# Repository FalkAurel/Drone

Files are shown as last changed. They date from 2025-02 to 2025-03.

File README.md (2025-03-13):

# 🚁 Custom Drone Project  

This project documents the complete process of designing, building, and programming a fully custom drone from scratch. Unlike many DIY drone projects, this one does **not** rely on any pre-existing drone components or software. Instead, every element—from hardware drivers to flight algorithms—is built from the ground up.  

## 🛠️ Project Overview  

- **Microcontroller:** ESP32 (used as the main driver)  
- **Design Software:** FreeCAD  
- **Hardware:** Fully custom-built, including motors, frame, and electronic components  
- **Software:** No pre-existing codebases; every driver is implemented based on hardware specifications  

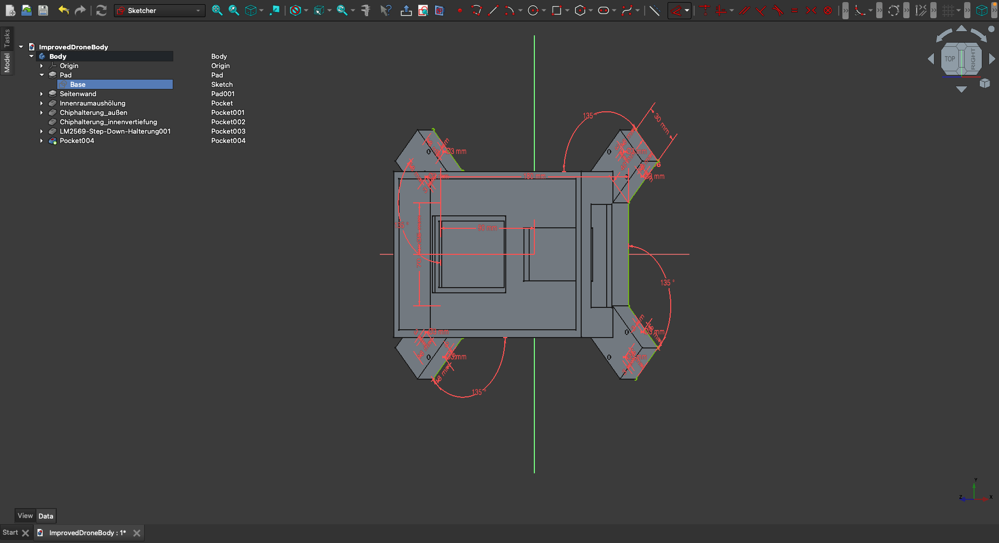
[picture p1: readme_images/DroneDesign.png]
Drone Design
  

## 📌 Features  

✅ **Custom Hardware Drivers** – Directly interact with components like gyrosensors and Electronic Speed Controllers (ESCs) without relying on third-party libraries.  
✅ **Fully Documented** – Every aspect of the project, from math equations to code logic, is extensively documented using comments and markdown files.  
✅ **Datasheets Included** – All hardware datasheets are attached to ensure transparency and reproducibility.  

## 🧠 Low-Level Hardware Control  

The codebase is built entirely from scratch, implementing precise control over essential components:  

- **Gyroscope Driver** – Interprets raw sensor data to maintain flight stability.  
- **ESC Control** – Generates PWM signals to regulate motor speed dynamically.  
- **Flight Algorithms** – Developed using mathematical models to achieve stable flight.  

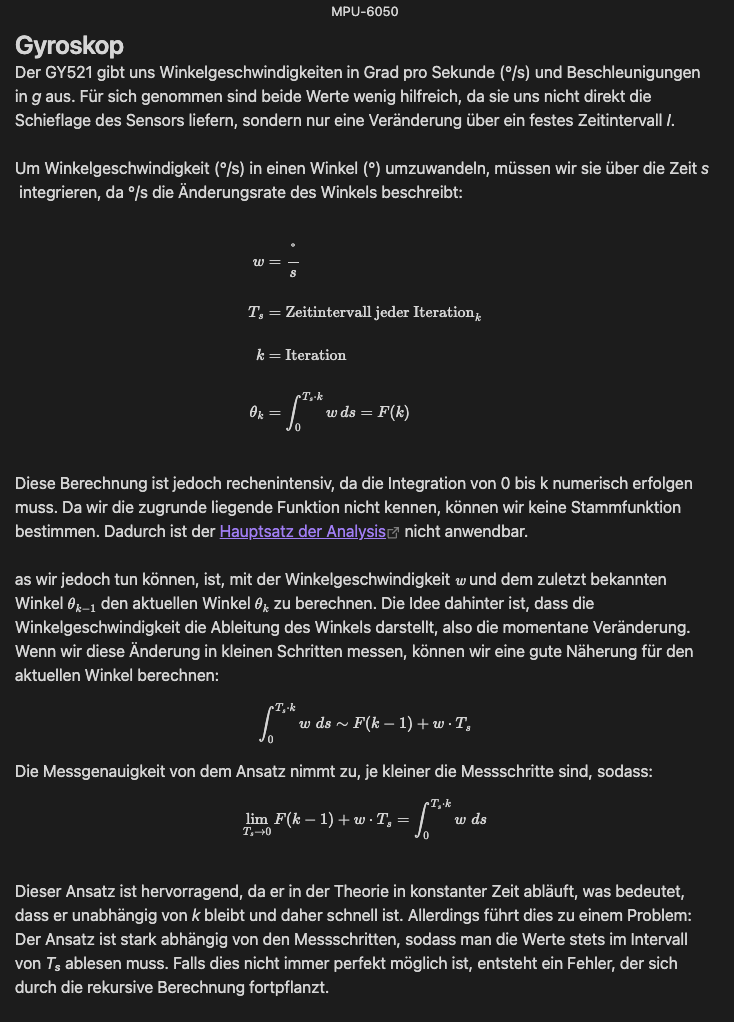
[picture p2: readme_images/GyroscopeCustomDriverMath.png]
Gyroscope Driver Math
  

## 📄 Documentation  

- **In-Depth Code Annotations** – Every function and logic structure is documented.  
- **Mathematical Derivations** – Flight physics, stabilization techniques, and control algorithms are explained.  
- **Reference Materials** – All datasheets and technical references are included.  

## ✅ Implemented Features  

- [x] ESP32-based flight controller  
- [x] Custom gyroscope driver  
- [x] Custom ESC driver  
- [x] Flight stabilization algorithms  
- [x] Complete design in FreeCAD  
- [x] Full documentation of code and math 
- [x] Custom Bump/Arena Allocator
- [x] Implement Wifi

## 📌 To-Do List
- [ ] Implement UDP or custom Data Transfer Protocol
- [ ] Implement Mulithreading
- [ ] Implement PID tuning for better flight stability
- [ ] Add remote control functionality
- [ ] Optimize power efficiency
- [ ] Improve motor calibration
- [ ] Perform real-world flight tests

## 🚀 Get Involved  

If you're interested in custom drone development, feel free to contribute, ask questions, or suggest improvements!

## Special Thanks
App Devlopment by [@MaeschDEV](https://github.com/MaeschDEV)

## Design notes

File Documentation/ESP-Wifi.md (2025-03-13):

Der ESP32 besitzt ein eingebautes Wifi-Modul. Das Wifi-Modul nutzt intern das Wifi -und Bluetoothradio. Diese Hardwarekomponente **muss** aktiviert werden. Anschließend muss entschieden werden, ob wir in STA oder AP-Modus schalten. Beide Modi haben Vor -und Nachteile, sodass oftmals eine STA/AP-Kombination gewählt wird.
In unserem Fall haben wir nur ein sehr eingeschränktes Nutzungsspektrum. Weshalb wir keine Kombination verwenden werden. 

| Modus | Anwendung |
| ----- | --- |
| AP | Der ESP32 stellt ein eigenes WLAN-Netzwerk bereit, mit dem sich andere Geräte verbinden können. Nützlich für lokale Steuerungen oder wenn keine bestehende Infrastruktur vorhanden ist. |
| STA | Der ESP32 verbindet sich mit einem bestehenden WLAN-Netzwerk, um Daten mit anderen Geräten oder dem Internet auszutauschen. Geeignet für IoT-Anwendungen und Cloud-Kommunikation. |
In unserem Fall wollen wir, dass die Drohne unabhängig von Netzempfang in der Natur funktioniert. Wichtig hierbei wird also die AP-Funktionalität sein. Die Drohne sollte ihr eigenes WLAN-Netzwerk bereitstellen. 

Um so etwas zu vollbringen, müssen wir die Drohne einrichten. Wir belassen viele Einstellungen bei den Standardeinstellungen.

| AP-Einstellungen  | Werte |
| --- | --- |
| SSID | Flightcontroller |
| Password | FlightcontrollerPassword |
| Sicherheit | WPA2Personal |
| max. Verbindungen | 2 |

Das ESP-Wifi nutzt statische IP-Adressen. Aus diesem Grund müssen die Wifi-Einstellungen von dem Endgerät auch angepasst werden.

| Wifi-Einstellungen | Werte |
| --- | --- |
| IP | Statisch (Standard ist DHCP) |
| IP-Adresse | 192.168.2.x (1 < x < 256) |

## Anwendung

Das ESPWifi-Modul muss erst kreiert werden.
```rust
let mut wifi: Wifi<Uninit> = Wifi::new(timg0.timer0, peripherals.RNG, peripherals.RADIO_CLK).unwrap();
```

Das ESPWifi-Modul muss anschließend initialisiert werden. Bei der Initialisierung werden SSID und Password gesetzt und die maximale Anzahl an zugelassenen Verbindungen.
```rust
wifi.init(peripherals.WIFI, "Flightcontroller", "FlightcontrollerPassword", 2).unwrap()
```
## Error

Das ESPWifi-Modul kann auf verschiedene Weisen verfehlen.

| Error | Grund |
| --- | --- |
| WifiRadioInitialization | Wifi -und Bluetoothradioaktivierung fehlerhaft |
| AccessPointConfig | Access Point Konfiguration fehlerhaft in Initialisierung |
| StartAP | Access Point start fehlerhaft in Initialisierung |
| UTF8Parsing | UTF8-String beinhaltet nicht ASCII-Code |

## UDP Layer

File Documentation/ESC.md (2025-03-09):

Quellen
- https://www.youtube.com/watch?v=oKFi5KRNqHE&t=31s

![[30A_BLDC_ESC_Product_Manual.pdf]]

Der 30A BLDC ESC ist ein elektronischer Speed Controller, der bei 5V und max. 3A arbeitet. Die Motoren werden durch [PWM](https://de.wikipedia.org/wiki/Pulsdauermodulation) angesteuert. Durch ein Kontrollsignal kann der ESC angesteuert werden. 

## PWM (Pulsdauermodulation)
https://en.wikipedia.org/wiki/Pulse-width_modulation

## Todo 
- Füge Pull-up wiederstande hinzu

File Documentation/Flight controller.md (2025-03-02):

```toml
[package]
edition = "2021"
name    = "flight_controller"
version = "0.1.0"

[[bin]]
name = "flight_controller"
path = "./src/bin/main.rs"

[dependencies]
embedded-io = "0.6.1"
embedded-io-async = "0.6.1"
esp-alloc = { version = "0.6.0" }
esp-backtrace = { version = "0.15.0", features = [
  "esp32",
  "exception-handler",
  "panic-handler",
  "println",
] }
esp-hal = { version = "0.23.1", features = ["esp32", "unstable"] } # defmt
esp-println = { version = "0.13.0", features = ["esp32", "log"] }
esp-wifi = { version = "0.12.0", default-features = false, features = [
  "ble",
  "coex",
  "esp-alloc",
  "esp32",
  #"log",
  #"utils",
  "wifi",
] }

heapless = { version = "0.8.0", default-features = false }
log = { version = "0.4.21"  } # https://docs.esp-rs.org/esp-hal/esp-wifi/0.12.0/esp32/esp_wifi/index.html
smoltcp = { version = "0.12.0", default-features = false, features = [
  "medium-ethernet",
  "multicast",
  "proto-dhcpv4",
  "proto-dns",
  "proto-ipv4",
  "socket-dns",
  "socket-icmp",
  "socket-raw",
  "socket-tcp",
  "socket-udp",
] }
# for more networking protocol support see https://crates.io/crates/edge-net
bleps = { git = "https://github.com/bjoernQ/bleps", package = "bleps", rev = "a5148d8ae679e021b78f53fd33afb8bb35d0b62e", features = [
  "async",
  "macros",
] }

critical-section = "1.2.0"
esp-hal-embassy = { version = "0.6.0", features = ["esp32"] }
static_cell = { version = "2.1.0", features = ["nightly"] }
libm = "0.2.11"
fugit = "0.3.7"

[profile.dev.package.esp-wifi]
opt-level = 3

[profile.dev]
# Rust debug is too slow.
# For debug builds always builds with some optimization
opt-level = "s"

[profile.release]
codegen-units    = 1     # LLVM can perform better optimizations using a single thread
debug            = 2
debug-assertions = false
incremental      = false
lto              = 'fat'
opt-level        = 's'
overflow-checks  = false
```

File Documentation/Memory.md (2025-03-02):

Dieses Modul dokumentiert die Implementierung einer eigenen Speicherverwaltung. Die Speicherverwaltung wird als [linked list alloctator](https://os.phil-opp.com/allocator-designs/#linked-list-allocator) implementiert. Weiterführend wird das ESP32 Technical Reference Manual ver. 5.3 verwendet. 

![[datasheets/ESP32_technical_reference.pdf]]

## Linked List Allocator

### Grundlegende Überlegungen

Der Linked List Allocator nutzt eine linked List, um die freien Speicherregionen zu verwalten. Die Idee ist, dass der Speicher sich selbst verwaltet, indem jeder Block auf den nächsten freien Block zeigt. Sobald kein Block mehr auf einen anderen zeigt, muss der Speicher voll sein. 

Zunächst beginnt man mit einem Block, der den ganzen Speicher abdeckt. Sobald Speicher benötigt wird, wird aus dem Block ein kleiner rausgeschnitten, der nun reserviert für eine Ressource genutzt wird. Das *"Rausschneiden"* beginnt immer am Anfang, sodass der Kopf der linked List auf immer auf den ersten freien Block zeigt.

Bei der Freigabe der speicherkonsumierenden Ressource wird auch der Speicher an den Allocator zurückgegeben. Das zurückgeben kann auf verschiedene Weisen funktionieren. Mann könnte versuchen den Block an seinen ursprünglichen Platz einzufügen oder ihn einfach an den Anfang der `free list` schieben. Beides hat Vor -und Nachteile.
Ersteres wäre der naive Ansatz, der theoretisch weniger Speicher pro Node header verbraucht, da die absolute Position nicht definiert werden muss, sondern durch die relative Lage in der `free list` bestimmt werden kann. Dieser Vorteil kommt auf Kosten der Laufzeit, da bei jedem `free` eine konstante Suche laufen muss (Theoretisch ist es eine O(*n*) Operation, aber da die Größe der `free_list` bereits durch den ersten Block definiert ist, hat sie eine feste obere Grenze, die sich nicht mehr verändern kann (definiert durch die Speichergröße)).
Wenn man aber jedem Block seine Adresse neben der Größe mitgibt (system width integer), dann kann man den Block einfach an den Anfang anhängen, sodass die Operation O(1) ist. Aus diesem Grund werden wir den letzteren Ansatz implementieren.

### Speicherfragmentierung

Jeder der eine linked List implementiert hat, weiß, dass sie kein kontinuierliches Speichersegment nutzt, sondern fragmentartig im Speicher lebt. Das ist zugleich die Stärke und Schwäche dieser Datenstruktur, es ermöglicht uns Sachen zu speichern, die nicht mehr in einem Stück in den Speicher passen, allerdings fragmentiert es auch den Speicher. Ein fragmentierter Speicher könnte theoretisch noch Elemente speichern, hätte er genug kontinuierlichen Speicher am Stück.
Die Fragmentierung hat zwei Ursachen: Alignment und unterschiedliche Objekte mit unterschiedlichen Lebenszeiten. 
Alignment ist nicht (leicht) zu beheben. Moderene Prozessoren sind darauf ausgelegt Daten von Adressen auszulesen, die ein vielfaches von 2 sind. Aus diesem Grund werden wir nicht dieses Problem angehen. 
Die Speicherfragmentierung durch Objekte mit verschiedenen Lebenszeit können wir softwaretechnisch angehen. Wir können nicht die Lebenszeiten der Objekte bestimmen, aber wir können die freigegebenen Speicherblöcke manipulieren. Wenn man zwei oder mehr Blöcke findet, die ein kontinuierliches Speichersegment beschreiben, kann man diese Blöcke in einen größeren zusammenführen. Eine weitere Vorgehensweise ist, `best-fit` Allokation zu nutzen. Wir suchen die ganze `free list` nach dem kleinsten passenden Block ab. Diese Optimierung sollte aber optional sein, da sie nicht effektiv in einem hot codepath ist.

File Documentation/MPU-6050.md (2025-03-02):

**Unser** Gyrosensor beinhaltet ein 3-Achsen-Gyroskop und einen 3-Achsen-Beschleunigungssensor. Und einige weitere Funktionalitäten, die nicht in unserem Kontext wichtig sind. Die MPU-60X0-Serie besitzt je drei 16-bit [ADC](https://de.wikipedia.org/wiki/Analog-Digital-Umsetzer) für Gyro -und Beschleunigungssensor. Damit ist ein leichtes Auslesen der Daten gewährleistet.
Weiterhin verfügt der Chip einen FIF0-1024-Bytes-Buffer, sodass man Bulk reads machen kann.

Unser Sensor nutzt intern den MPU-6050-IMU.
![[datasheets/MPU-6050-IMU-datasheet.pdf]]

Als Interface zu dem Chip nutzen wir den GY-521
![[gy-521_mpu-6050_3-axis_gyroscope_and_acceleration_sensor_en.pdf]]

## Konfigurationen

Der GY512 kann in Sachen Messmetriken und Messtoleranz konfiguriert werden. Die Konfiguration erfolgt über Register in die Werte geschrieben werden.

| Register | Funktion |
| --- | --- |
| `0x1A` | [DLPF](DLPF) und FSYNC |
| `0x1B` | GYRO_CONFIG |
| `0x1C` | ACCEL_CONFIG |
| `0x6B` | PWR_MGMT_1 |

## Power On

Der GY521 dient als eine Art von Schnittstelle zu dem unterliegenden Chip, dem MPU-6050. Der MPU-6050 ist also zunächst **nicht** eingeschaltet und befindet sich im Low-Power-Mode. Um den Chip aus dem Low-Power-Mode zu holen, schreibt man in das Register `0x6B` den Wert `0x0`.
Das Register `0x6B` ist für das Power Management zuständig. Der Wert `0x0` aktiviert eine 8Mhz (interne) CPU-Uhr. Es ist möglich eine bis zu 19.2Mhz anzuschließen, dass allerdings nur durch eine externes Signal. Für unsere Applikation ist das nicht von Nöten

![[MPU-6050-Register-0x6B.png]]

### Digital Low Pass Filter

Der Digital Low Pass Filter ermöglicht Signal von zu niedriger Frequenz auszufiltern, damit werden Störsignale gefiltert und das Signal bereinigt. 
![[MPU-6050-Register0x1A-Tabel.png]]

### Gyro Konfiguration

Mit dem Register können die °/s angegeben werden. 

![[MPU-6050-RegisterLayout-0x1B.png]]

Wobei die °/s  durch das `FS_SEL` angegeben wird.  `FS_SEL` kann folgende Werte haben:

| FS_SEL | Full Scale Range |
| --- | --- |
| 0 | ± 250 °/s |
| 1 | ± 500 °/s |
| 2 | ± 1000 °/s |
| 3 | ± 2000 °/s |

###   Beschleunigungssensor Konfiguration

Mit dem Register kann die Messgenauigkeit bis zu einer bestimmten `G`-Kraft definiert werden. Wie bei dem Gyroscope kann dafür ein Register verwendet werden, indem Fall ist es `0x1C`. Das Register `0x1C` ist identisch zu `0x1b`, nur werden die Werte anders interpretiert. 

![[MPU-6050-Register-0x1C.png]]

Die `AFS_SEL`-Bits definieren die G-Krafttoleranz. 

| AFS_SEL | Full Scale Range |
| --- | --- |
| 0 | ± 2g |
| 1 | ± 4g |
| 2 | ± 8g |
| 3 | ± 16g |

## Kommunikation

Der GY521 und der unterliegende MPU-6050 nutzen das [I²C](https://de.wikipedia.org/wiki/I²C)-Protokoll für den Datenaustausch. Der GY521 **startet immer als Slave** und erwartet von dem Master geweckt zu werden. Die Adresse des GY521 ist standardmäßig `0x68`. Sollte man den `AD0`-Pin auf high setzen, so nimmt der GY521 die Adresse `0x69` an. 

## Umrechnung in Winkel

## Gyroskop
Der GY521 gibt uns Winkelgeschwindigkeiten in Grad pro Sekunde (°/s) und Beschleunigungen in _g_ aus. Für sich genommen sind beide Werte wenig hilfreich, da sie uns nicht direkt die Schieflage des Sensors liefern, sondern nur eine Veränderung über ein festes Zeitintervall _I_.

Um Winkelgeschwindigkeit (°/s) in einen Winkel (°) umzuwandeln, müssen wir sie über die Zeit _s_ integrieren, da °/s die Änderungsrate des Winkels beschreibt:

$$
\begin{align}
w &= \dfrac{\degree}{s} \\[5mm]
T_s &= \text{Zeitintervall jeder Iteration}_k\\[5mm]
k &= \text{Iteration}\\[5mm]
\theta_k &= \int_0^{T_s \cdot k} w \, ds = F(k)
\end{align}
$$

Diese Berechnung ist jedoch rechenintensiv, da die Integration von 0 bis k numerisch erfolgen muss. Da wir die zugrunde liegende Funktion nicht kennen, können wir keine Stammfunktion bestimmen. Dadurch ist der [Hauptsatz der Analysis](https://de.wikipedia.org/wiki/Fundamentalsatz_der_Analysis) nicht anwendbar.

as wir jedoch tun können, ist, mit der Winkelgeschwindigkeit $\mathit{w}$ und dem zuletzt bekannten Winkel $\theta_{k-1}$ den aktuellen Winkel $\theta_k$ zu berechnen. Die Idee dahinter ist, dass die Winkelgeschwindigkeit die Ableitung des Winkels darstellt, also die momentane Veränderung. Wenn wir diese Änderung in kleinen Schritten messen, können wir eine gute Näherung für den aktuellen Winkel berechnen:
$$
\begin{align}
\int_0^{T_s \cdot k} w \,\,ds \sim F(k - 1) +w \cdot T_s
\end{align}
$$
Die Messgenauigkeit von dem Ansatz nimmt zu, je kleiner die Messschritte sind, sodass:
$$
\begin{align}
\lim_{T_s\to0} F(k - 1) +w \cdot T_s = \int_0^{T_s \cdot k} w \,\,ds
\end{align}
$$

Dieser Ansatz ist hervorragend, da er in der Theorie in konstanter Zeit abläuft, was bedeutet, dass er unabhängig von *k* bleibt und daher schnell ist. Allerdings führt dies zu einem Problem: Der Ansatz ist stark abhängig von den Messschritten, sodass man die Werte stets im Intervall von _Tₛ_ ablesen muss. Falls dies nicht immer perfekt möglich ist, entsteht ein Fehler, der sich durch die rekursive Berechnung fortpflanzt.

## Beschleunigungssensor

Der Beschleunigungssensor misst die Beschleunigung in Einheiten von _g_, wobei dieser Messwert die Beschleunigung entlang jeder Achse beschreibt. Wird der Sensor flach auf einen Tisch gelegt, erwartet man eine Beschleunigung von 1 _g_ entlang der Z-Achse und 0 _g_ entlang der X- und Y-Achsen. Wird der Sensor jedoch aufrecht hingestellt und um 90° entlang der X-Achse rotiert, misst er 1 _g_ entlang der X-Achse.

Durch einfaches Experimentieren lässt sich feststellen, dass die gemessene Beschleunigung entlang der Raumachsen in einer direkten Beziehung zur Orientierung des Sensors im Raum steht.

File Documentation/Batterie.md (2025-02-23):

Die Batterie muss zunächst den Spannungsbedarf der vier [Motoren](Brushless_Motor) decken. Der Spannungsbedarf liegt bei 11.1*V*. Jeder Motor kann bis zu 13A ziehen. Wir haben 4 Motoren, weshalb wir einen maximalen Stromstärkenverbrauch von 52A haben. 
Die Leistung der Batterie wird durch die Spannung und Amperestunden definiert. In unserem Fall ergibt sich die Formel:
$$
\begin{align}
Flugzeit &= \dfrac{Ah}{A} \\[5mm]

Flugzeit &= \dfrac{2.2Ah}{52A} = \dfrac{2.2h}{52} = 0.0423h = 2.538min
\end{align}
$$
0.04h sind 2.4min Betriebszeit. Aber unter normalen Bedingungen verbraucht die Drohne ca. 40% - 70% ihrer maximalen Stromstärke. Daraus ergibt sich ein gemittelter Verbrauch von 55%.
Wodurch sich unsere Betriebszeit fast verdoppelt:
$$
Flugzeit = \frac{2.2Ah}{52A} \cdot \frac{1}{0.55} = \frac{2.2Ah}{28.6A} = 0.0769h = 4.614min
$$

| Dimension | Maße |
| --- | ---- |
| Breite | 36 |
| Höhe | 23mm |
| Länge | 70mm |

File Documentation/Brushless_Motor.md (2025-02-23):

[Ressource](https://www.rotordronepro.com/guide-multirotor-motors/)

Die Wahl des Motors ist abhängig von der Größe und dem Gewicht der Drone. Der insgesamte Auftrieb des Motors sollte das doppelte des Gesamtgewichtes betragen.

## Nomenklatur
Brushless-Motoren sind in der Regel nach einer 4-stelligen Nummer sortiert. 

*DDMM*

*DD*: Dieser Wert gibt in Millimeter den Durchmesser des Motors an. 
*MM*: Dieser Wert gibt in Millimeter die Höhe des Motors an.

Je größer die Werte in *DD* und *MM*, desto mehr [Drehmoment](Physik/Drehmoment) kann der Motor aufbringen.

**KV**: beschreibt den theoretischen Anstieg von Umdrehungen pro Minute (RPM) mit jedem zusätzlichen Volt. Ein 2300 KV Motor auf eine 12.6 V Batterie könnte theoretisch 28980 RPM erreichen. 
Je höher die **KV**, desto höher die Drehgeschwindigkeit und niedriger das Drehmoment. Also haben Motoren mit einem niedrigeren **KV**-Wert ein höheres Drehmoment mit niedriger Rotationsgeschwindigkeit.

###  N und P

Die Nummer vor dem **N** gibt an, wieviele Elektromagneten in dem Stator vorhanden sind. 
Die Nummer vor dem **P** gibt an, wieviele Dauermagnete in dem Motor vorhanden sind.

### Tabellarische Übersicht

Diese Tabelle stellt gewöhnliche Motorkonfigurationen in Bezug zu der Dronengröße her

| Frame Size | Prop Size  | Motor Size | KV |
| --- | --- | --- | --- |
| <= 150mm | 3'' >= | 1306 >= | 3000 <= |
| 180mm | 4'' | 1806 | 2600 |
| 210mm | 5'' | 2204-2206  | 2300-2600 |
| 250mm | 6'' | 2204-2208  | 2000-2300 |
| 350mm | 7'' | 2208 | 1600 |
| 450mm | 8''...10'' | 2212 <= | 1000 >= |

## Unser Motor

### A2212 10T 1400KV

Weitere Quellen
- https://components101.com/motors/2212-brushless-motor
- https://www.4-max.co.uk/A2212-10T-1400kv.htm
- 

| Voltage Input Range | 6V ~12.6 V |
| --- | --- |
| Voltage Input Range | 6V ~12.6 V |
| Schub | 555g |
| Höhst Ampereverbrauch | 13A |

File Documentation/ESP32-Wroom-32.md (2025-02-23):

## Überblick

[ESP32 mit CH340 Entwicklungsplatine](https://www.amazon.de/Entwicklungsplatine-Binghe-ESP-WROOM-32-Bluetooth-kompatibel/dp/B0D8635YZ6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ÅMÅŽÕÑ&crid=U6S6FM8RXKHQ&dib=eyJ2IjoiMSJ9.sNY-5N5qC7Qc40Mxm97ZN4weJ778AWoug6y_-HIs7zJnUx6G5a_Cr7ui9T0AqxXx3C38nRJsddtw9oVz7HkEjisz5nsbp02URqzqz5KKdO1C33Xk-TpJYW610M7W6_PBUIUInRioKLPqgdexH6gLK1X_Ba-g42B5osPiGoGjxDhPiUmD_AIm_dKic2TON03oMuE5Va2wzURmNc_jQgbxTkYLvc-ipVYjj0HAakPXDNg.EPnLuabGVGk9OuytN7jRzqsqm6UfvlIYVpuc6GJIAZM&dib_tag=se&keywords=ESP32+ESP-32S+Development+Board+%283pcs%29&qid=1739624362&sprefix=esp32+esp-32s+development+board+3pcs+%2Caps%2C102&sr=8-9) ist ein Chip mit WiFi -und Bluetoothanbindung. Intern wird ein [ESP32-DOWDQ6-Chip](https://www.espressif.com/sites/default/files/documentation/esp32_datasheet_en.pdf) verwendet.
Die technischen Hardwaredaten des Chips sind hier gelistet:

| Item | Spezifikation |
| --- | --- |
| Integrierter Kristall | 40Mhz |
| SPI flash | 4MB |
| Operating voltage / Power supply | 3.0 ~3.6V |
| Operating Current | Average: 80mA |
| Minimum current delivered by power supply | 500mA |
| Package size | 18mm x 25.5mm x 3.10mm |
| CPU Architecture | dual-core [Xtensa]() 32-bit LX6 microprocessor |

Weitere Daten sind im Datenblatt zu finden, für die jetzige Implementation langen die Daten.

## Pin Definitionen

![[ESP32-Wroom-32-Pinout.jpg]]

| Name | No. | Type | Function |
| --- | --- | ---- | --- |
| GND | 1 | P | Ground |
| 3V3 | 2 | P | Power supply |
| EN | 3 | I | Module-enable signal. Active high |
| SENSOR_VP | 4 | I | GPIO36, ADC1_CH0, RTC_GPIO0 |
| SENSOR_VN | 5 | I | GPIO39, ADC1_CH3, RTC_GPIO3 |
| IO34 | 6 | I | GPIO34, ADC1_CH6, RTC_GPIO4 |
| IO35 | 7 | I | GPIO35, ADC1_CH7, RTC_GPIO5 |
| IO32 | 8 | I/O  | GPIO32, XTAL_32K_P (32.768 kHz crystal oscillator input), ADC1_CH4, TOUCH9, RTC_GPIO9  |
| IO33 | 9 | I/O  | GPIO33, XTAL_32K_N (32.768 kHz crystal oscillator output), ADC1_CH5, TOUCH8, RTC_GPIO8 |
| IO25 | 10  | I/O  | GPIO25, DAC_1, ADC2_CH8, RTC_GPIO6, EMAC_RXD0 |
| IO26 | 11  | I/O  | GPIO26, DAC_2, ADC2_CH9, RTC_GPIO7, EMAC_RXD1 |
| IO27 | 12  | I/O  | GPIO27, ADC2_CH7, TOUCH7, RTC_GPIO17, EMAC_RX_DV |
| IO14 | 13  | I/O  | GPIO14, ADC2_CH6, TOUCH6, RTC_GPIO16, MTMS, HSPICLK, HS2_CLK, SD_CLK, EMAC_TXD2 |
| IO12 | 14  | I/O  | GPIO12, ADC2_CH5, TOUCH5, RTC_GPIO15, MTDI, HSPIQ, HS2_DATA2, SD_DATA2, EMAC_TXD3 |
| GND | 15  | P | Ground |
| IO13 | 16  | I/O  | GPIO13, ADC2_CH4, TOUCH4, RTC_GPIO14, MTCK, HSPID, HS2_DATA3, SD_DATA3, EMAC_RX_ER |
| SHD/SD2*  | 17  | I/O  | GPIO9, SD_DATA2, SPIHD, HS1_DATA2, U1RXD |
| SWP/SD3*  | 18  | I/O  | GPIO10, SD_DATA3, SPIWP, HS1_DATA3, U1TXD |
| SCS/CMD*  | 19  | I/O  | GPIO11, SD_CMD, SPICS0, HS1_CMD, U1RTS |
| SCK/CLK*  | 20  | I/O  | GPIO6, SD_CLK, SPICLK, HS1_CLK, U1CTS |
| SDO/SD0*  | 21  | I/O  | GPIO7, SD_DATA0, SPIQ, HS1_DATA0, U2RTS |
| SDI/SD1*  | 22  | I/O  | GPIO8, SD_DATA1, SPID, HS1_DATA1, U2CTS |
| IO15 | 23  | I/O  | GPIO15, ADC2_CH3, TOUCH3, MTDO, HSPICS0, RTC_GPIO13, HS2_CMD, SD_CMD, EMAC_RXD3 |
| IO2 | 24  | I/O  | GPIO2, ADC2_CH2, TOUCH2, RTC_GPIO12, HSPIWP, HS2_DATA0, SD_DATA0 |
| IO0 | 25  | I/O  | GPIO0, ADC2_CH1, TOUCH1, RTC_GPIO11, CLK_OUT1, EMAC_TX_CLK |
| IO4 | 26  | I/O  | GPIO4, ADC2_CH0, TOUCH0, RTC_GPIO10, HSPIHD, HS2_DATA1, SD_DATA1, EMAC_TX_ER |
| IO16 | 27  | I/O  | GPIO16, HS1_DATA4, U2RXD, EMAC_CLK_OUT |
| IO17 | 28  | I/O  | GPIO17, HS1_DATA5, U2TXD, EMAC_CLK_OUT_180 |
| IO5 | 29  | I/O  | GPIO5, VSPICS0, HS1_DATA6, EMAC_RX_CLK |
| IO18 | 30  | I/O  | GPIO18, VSPICLK, HS1_DATA7 |
| IO19 | 31  | I/O  | GPIO19, VSPIQ, U0CTS, EMAC_TXD0 |
| NC | 32  | - | - |
| IO21 | 33  | I/O  | GPIO21, VSPIHD, EMAC_TX_EN |
| RXD0 | 34  | I/O  | GPIO3, U0RXD, CLK_OUT2 |
| TXD0 | 35  | I/O  | GPIO1, U0TXD, CLK_OUT3, EMAC_RXD2 |
| IO22 | 36  | I/O  | GPIO22, VSPIWP, U0RTS, EMAC_TXD1 |
| IO23 | 37  | I/O  | GPIO23, VSPID, HS1_STROBE |
| GND | 38  | P | Ground |

## Einrichten einer Rust-Entwicklungsumgebung

Der ESP32-WROOM kann in Rust sowohl in `no_std` als auch in `std` beschrieben werden. Die Besonderheit liegt in der Leistung und Entwicklungsgeschwindigkeit. Für schnelle, rapide Entwicklung eignet sich die `std`-Version, während `no_std` für Leistung gedacht ist.
Für dieses Projekt nutzen wir erst die `std`-Version, sollte irgendwann Leistung ein Problem werden, werden wir den Code umschreiben in die `no_std`-Version.
In beiden Fällen müssen wir für die [Xtensa](https://dl.espressif.com/github_assets/espressif/xtensa-isa-doc/releases/download/latest/Xtensa.pdf)-Architektur kompilieren. Dafür nutzt man einen [Cross-Compiler](https://de.wikipedia.org/wiki/Cross-Compiler). Rust kann das automatisch, da es LLVM als Compiler-Backend verwendet, weshalb wir nur noch die Architektur spezifizieren müssen.
Weiterhin werden wir die virtuelle Umgebung [Docker](https://www.docker.com) verwenden, da ich die Toolchain nicht  auf meinem System einrichten kann und man am Ende nur noch das Docker Image entfernen muss, wenn man mit dem Projekt fertig ist.

### Installieren von Rust Templates

Mit den folgenden Modulen lassen sich Rust-Projekt-Templates generieren. Das ist optional, jedoch empfohlen, da diese eine lokale Toolchain spezifizieren. 

- [cargo-generate](https://crates.io/crates/cargo-generate) Templategenerator. Nutzt bereits git repositories, um ein Projekttemplate zu generieren
- [espflash](https://github.com/esp-rs/espflash) ermöglicht das Brennen und Löschen von Code. Weiterhin kann es den Serial-Port in der Konsole ausgeben
- [esp-generate](https://github.com/esp-rs/esp-generate) Templategenerator für `no_std`

```bash
cargo install cargo-generate espflash esp-generate
```

Es gibt zwei Möglichkeiten, um ein Projekt zu generieren:
1. Man nutzt `esp-generate`, um ein `no_std` Projekt herzustellen.
2.  Man nutzt `cargo generate esp-rs/esp-idf-template cargo` um ein `std`Projekt  herzustellen.
In beiden Fälle muss man in den Erstelloptionen `devcontainer` hinzufügen.

In beiden fällen wird im Hauptreiter des Projektes ein Ordner namens `.devcontainer`, welcher unsere `Dockerfile` enthält. 

Um das Dockerimage zu bauen nutze diesen Befehl:

```bash
docker image build -t <name> -f .devcontainer/Dockerfile .
```

Um es auszuführen nutze diesen Befehl:

```
docker run --mount type=bind,source="$(pwd)",target=/workspace,consistency=cached -it <name> /bin/bash
```

Ich empfehle für den letzteren Befehl einen Shortcut im Projekt anzulegen, anstatt den Befehl immer auszuschreiben, nutze ein ShellScript:

```bash
echo "docker run --mount type=bind,source="$(pwd)",target=/workspace,consistency=cached -it <name> /bin/bash" >> start_docker.sh
```

Je nach Dockerfile Konfiguration, hat man einen anderen Startpunkt. Um das Projekt ausführen muss man in den **workspace** Ordner navigieren, sofern man in Docker Zugang zu USB-Serial-Peripherals hat, kann man einfach sein Projekt mit `cargo run` ausführen und auf den Chip brennen. 
Andernfalls muss man mit `cargo build` die ELF-Datei bauen und dann manuell in der natürlichen Umgebung, also außerhalb von Docker, mit `espflash` auf den Chip bringen.

## Pin Mapping

| Pin | Purpose |
| --- | --- |
| 21  | SDA ([MPU-6050](MPU-6050.md)) |
| 22  | SCL([MPU-6050](MPU-6050.md))  |
| | |

## Nützliche Ressourcen

- https://docs.sunfounder.com/projects/esp32-starter-kit/en/latest/components/component_esp32_extension.html
-

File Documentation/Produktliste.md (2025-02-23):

[Motorset](https://www.amazon.de/-/en/Brushless-Outrunner-Aircraft-KKmulticopter-Quadcopter/dp/B07VR9FR6R?th=1)
[Gyrosensor MPU6050](https://www.amazon.de/ARCELI-Beschleunigungssensor-Motion-Sensing-Spiele-Fußgänger-Navigatoren-Haltungs-Verknüpfungen/dp/B0CLS2JY43/ref=sr_1_4?dib=eyJ2IjoiMSJ9.Q1s4aL4ayXqk7UIPMXERyoUjo7V3x9kSy2_3wUMEX3W-j7ZHBimOVjXUfKHPS_QvJ-W93_beybfy9Ib0V8I2ghw3DEcoKUuRvoelAoWNJaxvq8mEVNC7bP0dFBZRtbTm8dxX-kcHN5gIEbdduI8ZfIpOwxzw37atD5U66KBVW4ffu6EWG73vCWATkODSq2OaV09XmXFpXYg2p5tPxm86MjZWlJ_y_-yEE-TeBphQe-A.QeQRLMoQNpzT0iRAtsUzZL6A19gBbmvWm5ddlR2oMFo&dib_tag=se&keywords=mpu6050&qid=1739530825&sr=8-4)
[Akku]()
[ESC](https://www.amazon.de/gp/product/B0BD3XTBLD/ref=ewc_pr_img_1?smid=AHJIHYSV33HO3&psc=1)

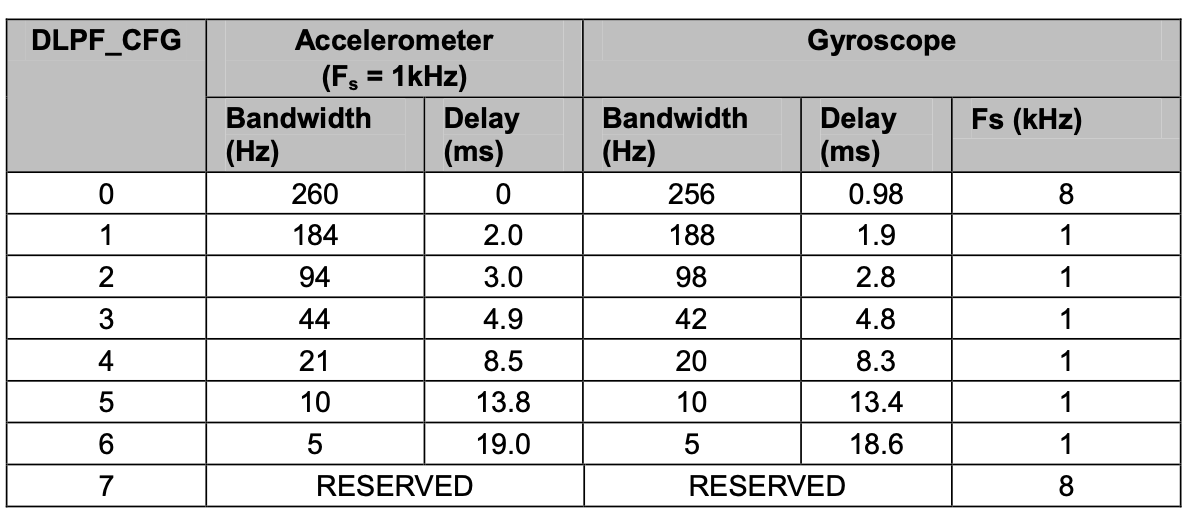
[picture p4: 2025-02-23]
Documentation/Images/MPU-6050-Register0x1A-Tabel.png

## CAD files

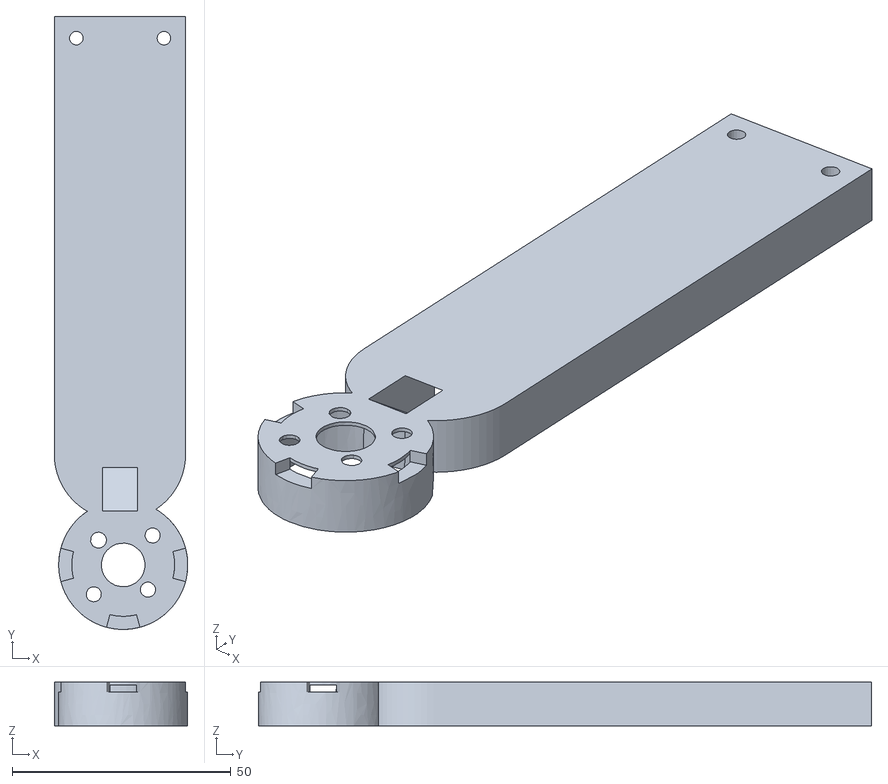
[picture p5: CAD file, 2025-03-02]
Designs/drone_rotor.stl
30.5 x 140.0 x 10.0

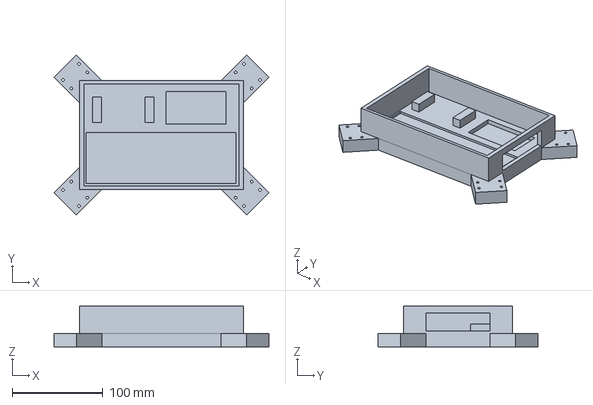
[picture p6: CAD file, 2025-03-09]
Designs/FreeCad/ImprovedDroneBody.FCStd
236.6 x 176.1 x 45.0 mm

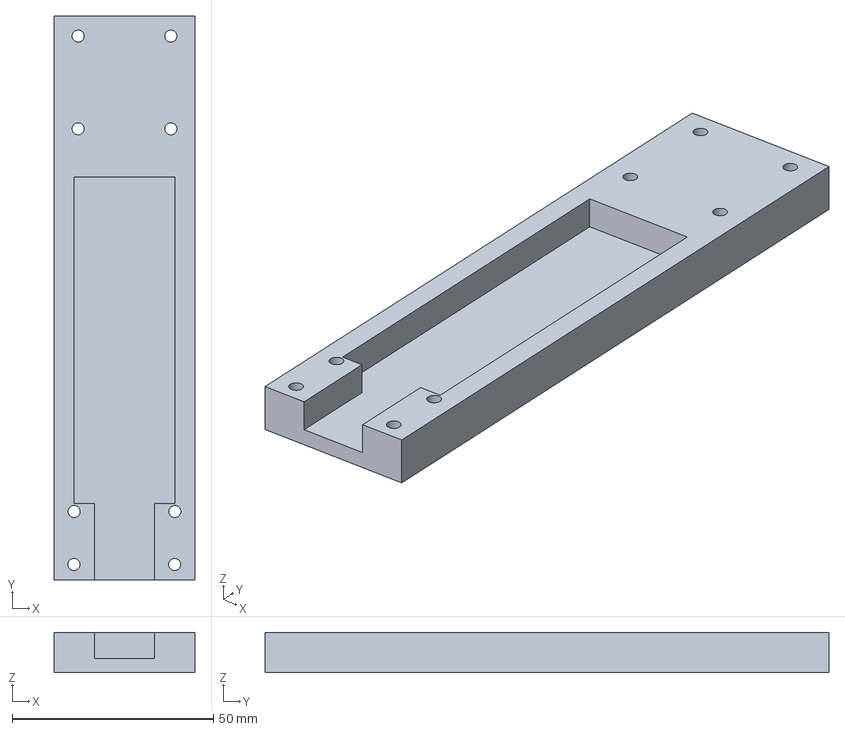
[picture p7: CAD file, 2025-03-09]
Designs/FreeCad/DroneRotorHolding.FCStd
35.0 x 140.0 x 10.0 mm

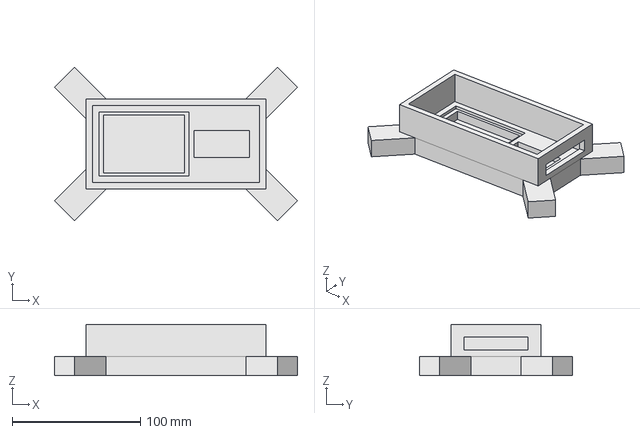
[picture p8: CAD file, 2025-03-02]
Designs/FreeCad/Drohne Julius.FCStd
189.5 x 119.5 x 40.0 mm

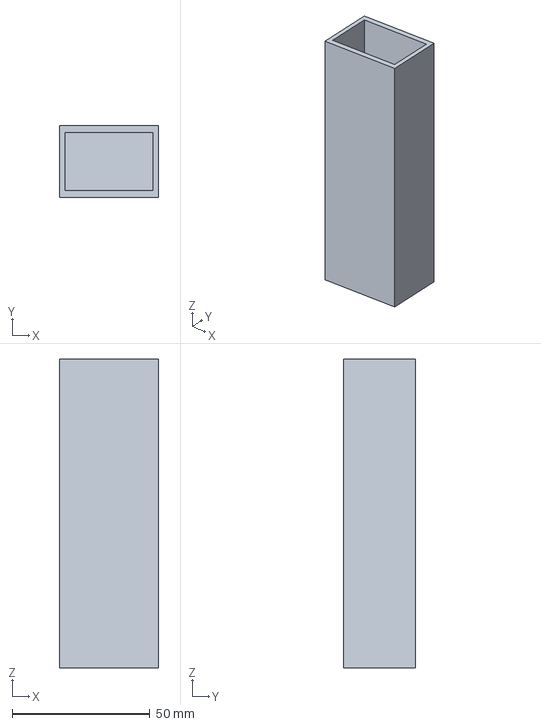
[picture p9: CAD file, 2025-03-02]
Designs/FreeCad/BatteryCase.FCStd
36.0 x 26.0 x 112.0 mm

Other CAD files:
Designs/BatteryCase.stl
Designs/DroneRotorHolding.stl
Designs/FreeCad/DroneRotorHolding.stl
Designs/FreeCad/ImprovedDroneBody.stl
Designs/ImprovedDroneBody.stl

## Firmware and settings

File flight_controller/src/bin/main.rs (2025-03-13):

#![no_std]
#![no_main]
#![feature(allocator_api)]

use esp_backtrace as _;
use esp_hal::clock::CpuClock;
use esp_hal::peripherals::{Peripherals, TIMG0};
use esp_hal::Config;
use esp_hal::timer::timg::TimerGroup;
use flight_controller::esc::{ESCControler, RotorStrength};

#[esp_hal::main]
fn main() -> ! {
    // generator version: 0.2.2
    let config: Config = Config::default().with_cpu_clock(CpuClock::max());
    let peripherals: Peripherals = esp_hal::init(config);

    esp_println::logger::init_logger_from_env();

    if cfg!(feature = "wifi") {
        wifi_main(peripherals)
    } else {
        #[cfg(not(feature = "wifi"))]
        regular_main(peripherals);
        loop {}
    }
    // for inspiration have a look at the examples at https://github.com/esp-rs/esp-hal/tree/v0.23.1/examples/src/bin
}


#[cfg(feature = "wifi")]
fn wifi_main(peripherals: Peripherals) -> ! {
    use flight_controller::{wifi::*, mem::init_heap};
    use core::net::Ipv4Addr;

    init_heap();
    let timer_group: TimerGroup<TIMG0> = TimerGroup::new(peripherals.TIMG0);
    let wifi: Wifi<Init> = Wifi::new(timer_group.timer0, peripherals.RNG, peripherals.RADIO_CLK)
    .unwrap()
    .init(peripherals.WIFI, "Flightcontroller", "Password123", 255)
    .unwrap();

    // 192.168.2.1
    setup_udp_socket(wifi, Ipv4Addr::new(192, 168, 2, 1));
}

#[cfg(not(feature = "wifi"))]
fn regular_main(peripherals: Peripherals) {
    let mut esc_controller: ESCControler = ESCControler::new(
        peripherals.LEDC, peripherals.GPIO27, peripherals.GPIO26, peripherals.GPIO25, peripherals.GPIO23
    ).unwrap();

    esc_controller.init().unwrap();
    esc_controller.update_rotor_frequency(RotorStrength::new(0, 50, 0, 0)).unwrap();
}

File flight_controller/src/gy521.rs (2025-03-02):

use esp_hal::{
    delay::Delay, 
    gpio::GpioPin, 
    i2c::master::{Config, Error, I2c}, 
    peripherals::I2C0, 
    Blocking
};

use sensor_data::{CalibrationOffsets, ScalingFactor};

// Re-export
pub use sensor_data::{AccelometerData, GyroscopeData, DataFrame};
pub use mpu_configuration::{Config as MPUConfig, Dlpf, AFullRangeScale, GFullRangeScale};


// Follow chip specification: MPU-6050-Register-Mapping.pdf
const MPU_ADDRESS: u8           =  0x68;
const WAKE_UP_SEQUENCE: [u8; 2] = [0x6B, 0x0];

// These 
const ACCELO_READ_ADDR: u8 = 0x3B;
const GYRO_READ_ADDR: u8   = 0x43; // This address is the start

// Configuration Register Adress
const DLPF_CONFIG_ADDR: u8   = 0x1A;
const GYRO_CONFIG_ADDR: u8   = 0x1B;
const ACCELO_CONFIG_ADDR: u8 = 0x1C;

// This modul serves with configu
mod mpu_configuration {
    use super::sensor_data::ScalingFactor;

    // https://en.wikipedia.org/wiki/Low-pass_filter
    #[repr(u8)]
    #[allow(non_camel_case_types, dead_code)]
    pub enum Dlpf {
        Hz_256 = 0,
        Hz_188 = 1,
        Hz_98  = 2,
        Hz_42  = 3,
        Hz_20  = 4,
        Hz_10  = 5,
        Hz_5   = 6
    }
    
    #[repr(u8)]
    #[allow(non_camel_case_types, dead_code)]
    pub enum GFullRangeScale {
        Sel_250  = 0 << 3,
        Sel_500  = 1 << 3,
        Sel_1000 = 2 << 3,
        Sel_2000 = 3 << 3
    }

    #[repr(u8)]
    #[allow(non_camel_case_types, dead_code)]
    pub enum AFullRangeScale {
        Sel_2g  = 0 << 3,
        Sel_4g  = 1 << 3,
        Sel_8g  = 2 << 3,
        Sel_16g = 3 << 3
    }

    pub struct Config {
        pub(crate) dlpf: Dlpf,        
        pub(crate) a_fs: AFullRangeScale,
        pub(crate) g_fs: GFullRangeScale
    }

    impl Config {
        pub (crate) fn get_scaling_factor(&self) -> ScalingFactor {
            let a: f32 = match self.a_fs {
                AFullRangeScale::Sel_2g => 16384.0,
                AFullRangeScale::Sel_4g => 8192.0,
                AFullRangeScale::Sel_8g => 4096.0,
                AFullRangeScale::Sel_16g => 2048.0
            };

            let g: f32 = match self.g_fs {
                GFullRangeScale::Sel_250 => 131.0,
                GFullRangeScale::Sel_500 => 65.5,
                GFullRangeScale::Sel_1000 => 32.8,
                GFullRangeScale::Sel_2000 => 16.4
            };

            ScalingFactor {a, g}
        }

        pub fn set_afs(mut self, afs: AFullRangeScale) -> Self {
            self.a_fs = afs;
            self
        }

        pub fn set_gfs(mut self, gfs: GFullRangeScale) -> Self {
            self.g_fs = gfs;
            self
        }

        pub fn set_dlpf(mut  self, dlpf: Dlpf) -> Self {
            self.dlpf = dlpf;
            self
        }
    }

    impl Default for Config {
        fn default() -> Self {
            Self { dlpf: Dlpf::Hz_20, a_fs: AFullRangeScale::Sel_8g, g_fs: GFullRangeScale::Sel_1000 }
        }
    }
}


// This module serves data interpretation
mod sensor_data {
    pub (crate) struct CalibrationOffsets {
        pub(crate) ax: i16,
        pub(crate) ay: i16,
        pub(crate) az: i16,
        pub(crate) gx: i16,
        pub(crate) gy: i16,
        pub(crate) gz: i16
    }

    impl Default for CalibrationOffsets {
        fn default() -> Self {
            Self { ax: 0, ay: 0, az: 0, gx: 0, gy: 0, gz: 0 }
        }
    }

    pub (crate) struct ScalingFactor {
        pub(crate) a: f32,
        pub(crate) g: f32,
    }

    #[derive(Debug)]
    pub struct AccelometerData {
        pub x: f32,
        pub y: f32,
        pub z: f32
    }

    #[derive(Debug)]
    pub struct GyroscopeData {
        pub x: f32,
        pub y: f32,
        pub z: f32
    }

    #[derive(Debug)]
    pub struct DataFrame {
        accel: AccelometerData,
        gyro: GyroscopeData
    }

    impl DataFrame {
        pub (crate) fn new(a_bytes: [u8; 6], g_bytes: [u8; 6], scaling_factor: &ScalingFactor, calibration: &CalibrationOffsets) -> Self {
            let &CalibrationOffsets { ax, ay, az, gx, gy, gz } = calibration;
            let (a_x, a_y, a_z) = Self::get_sensor_data(a_bytes, ax, ay, az,scaling_factor.a);
            let (g_x, g_y, g_z) = Self::get_sensor_data(g_bytes, gx, gy, gz, scaling_factor.g);
            
            Self { accel: AccelometerData { x: a_x, y: a_y, z: a_z }, gyro: GyroscopeData { x: g_x, y: g_y, z: g_z } }
        }

        fn get_sensor_data(bytes: [u8; 6], cal_x: i16, cal_y: i16, cal_z: i16, scaling_factor: f32) -> (f32, f32, f32) {
            let x: f32 = i16::checked_sub(
                i16::from_be_bytes([bytes[0], bytes[1]]),
                 cal_x
            ).unwrap_or_else(|| if cal_x > 0 { i16::MIN } else { i16::MAX }) as f32;

            let y: f32 = i16::checked_sub(
                i16::from_be_bytes([bytes[2], bytes[3]]), 
                cal_y
            ).unwrap_or_else(|| if cal_y > 0 { i16::MIN } else { i16::MAX }) as f32; 
            
            let z: f32 = i16::checked_sub(
                i16::from_be_bytes([bytes[4], bytes[5]]), 
                cal_z
            ).unwrap_or_else(|| if cal_z > 0 { i16::MIN } else { i16::MAX }) as f32;

            (x / scaling_factor, y / scaling_factor, z / scaling_factor)
        }

        pub fn get_accel(&self) -> &AccelometerData {
            &self.accel
        }

        pub fn get_gyro(&self) -> &GyroscopeData {
            &self.gyro
        }
    }
}

pub struct GY521<'driver> {
    master: I2c<'driver, Blocking>,
    scaling_factor: Option<ScalingFactor>,
    calibration_offsets: CalibrationOffsets,
}
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

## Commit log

2025-03-02 Adding custom memory allocator for the esp32. This is the foundation for the wifi module. Before we implement the wifi module, I'll probably optimize the Allocator to merge freeed memory blocks to co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
    [BatteryCase.FCStd, Drohne Julius.FCStd, Drohne.stl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]
2025-03-09 Fix misalignment issues by implementing hybrid Arena/BumpAllocator
    This fix required deep debugging, including reviewing memory layout in the TRM.
    The new allocator is a hybrid mix of an Arena and a BumpAllocator.
    While not the most memory-efficient, it is extremely fast and only frees memory
    when everything has been dropped.
    With up to 4MiB of SRAM, delayed memory freeing is negligible.
    **Important for future use:** Always set the feature flag,
    or external RAM will not be mapped into the address space.
    Safety commit
    [BatteryCase.stl, DroneRotorHolding.FCStd, DroneRotorHolding.stl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]
2025-03-13 Adding a WIFI-Driver to enable networking. Currently the Wifi module is set up to serve as an AP. This might change in the future
